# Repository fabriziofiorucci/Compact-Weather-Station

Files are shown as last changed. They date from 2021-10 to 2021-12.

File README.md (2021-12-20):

# Compact weather station

## Description

This is a MQTT-enabled, compact weather station powered by a Wemos D1 minicontroller and built with 3D-printed parts. It supports OTA updates.
The weather station is meant to be screwed on a windowsill.

Used sensors and parts are:

- Wemos D1 minicontroller
- Wind speed: Anemometer with analog voltage output (like https://www.adafruit.com/product/1733)
- Visible light: GY-30 BH1750 Ambient light sensor module
- Air quality/pollution: Digital Particle Concentration Laser Sensor PMS5003
- Rain quantity: Tipping bucket rain gauge (like https://www.bc-robotics.com/shop/tipping-rain-gauge/)
- Rain level: Capacitive soil moisture sensor
- Temperature, humidity, pressure: BME280 Humidity & Pressure Sensor
- Wind speed decoding: ADS1115 16-Bit ADC - 4 Channel with Programmable Gain Amplifier
- LM7805 linear voltage regulator
- 1x 1.8kohm resistor
- 2, 3 & 4 pins JST XH connectors
- 2 & 3 poles PCB screw terminal blocks
- 12V 2A power supply
- M3 Torx screws and bolts
- Cable glands
- 2.54mm / 1 inch PVC pipe

This project is on Thingiverse at https://www.thingiverse.com/thing:5027011

## Schematics

The circuit can be quickly built on a single layer perfboard. It can be powered by a 12V 2A power supply. The onboard LM7805 generates the 5V voltage required for most components. The BME280 sensor is powered at 3.3v directly from the Wemos D1.



## Wemos D1 sketch 

The Wemos sketch can be uploaded using Arduino IDE. The software periodically polls sensors and publishes all readings through MQTT. To reduce wear and extend service life, PMS5003 laser is switched off when not reading.
Over-The-Air updates are supported with no need to physically access the Wemos unit.

The sketch must be configured to point to your MQTT broker and to connect to your WiFi network (see "CUSTOMIZE HERE" sessions)

It relies on https://github.com/SwapBap/PMS for PMS5003 communication

## 3D components

All parts should be printed using:

- weatherproof filament (ASA or PETG)
- 3 walls
- 0.1mm layer height
- print plate adhesion raft in case it's needed

The Stevenson shield is https://www.thingiverse.com/thing:1053967 printed at 40% of the original size:

- Stevenson_screen_Side_Ring.STL (print 17 times)
- Stevenson_screen_Cover.STL (print once)
- Stevenson_screen_Base.STL (print once)
- 220mmX190mm_Internal_Bracket_for_14_Side_Rings.STL (print once)

The Anemometer 1/4-20 adapter is Anemometer_Adapter_riser_version.stl, from https://www.thingiverse.com/thing:2710360

## Complete build

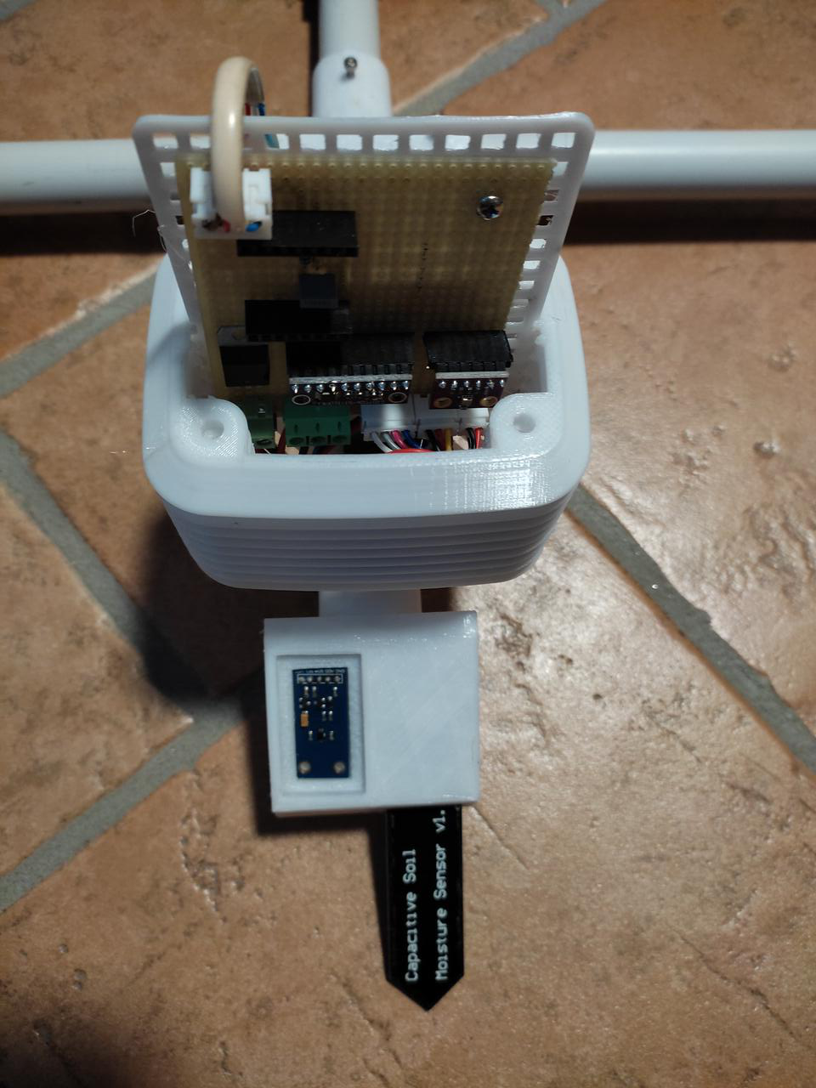
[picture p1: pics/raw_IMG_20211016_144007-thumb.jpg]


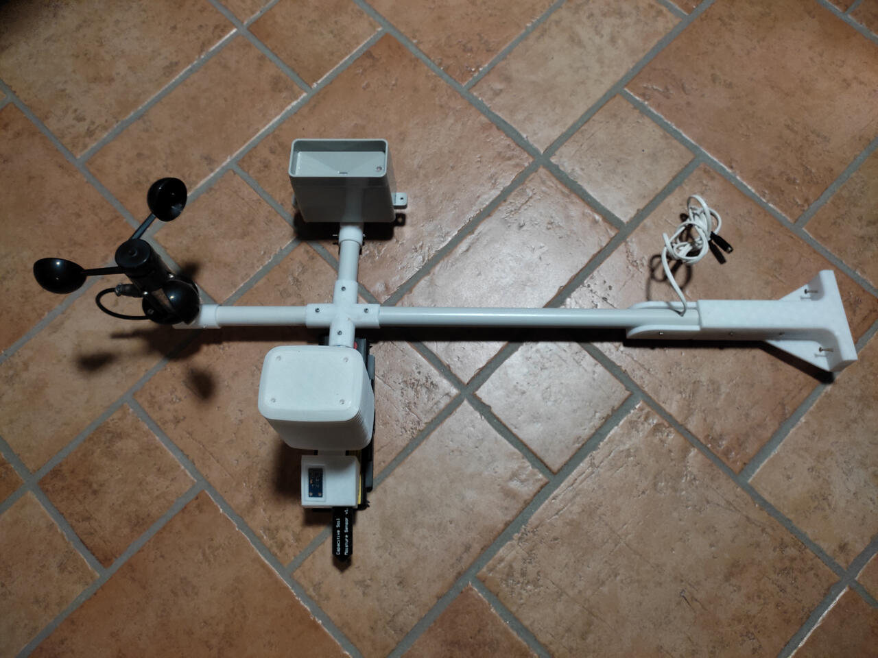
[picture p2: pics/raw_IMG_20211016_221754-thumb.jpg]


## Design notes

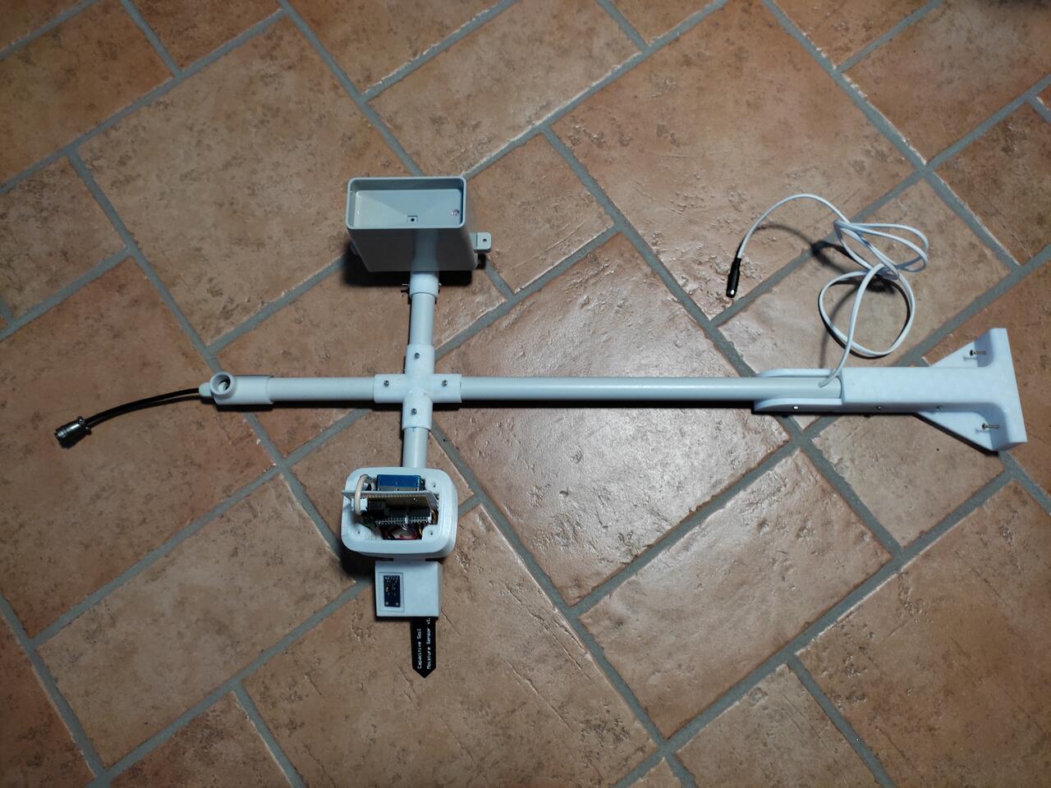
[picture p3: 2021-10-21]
pics/raw_IMG_20211016_144035-thumb.jpg

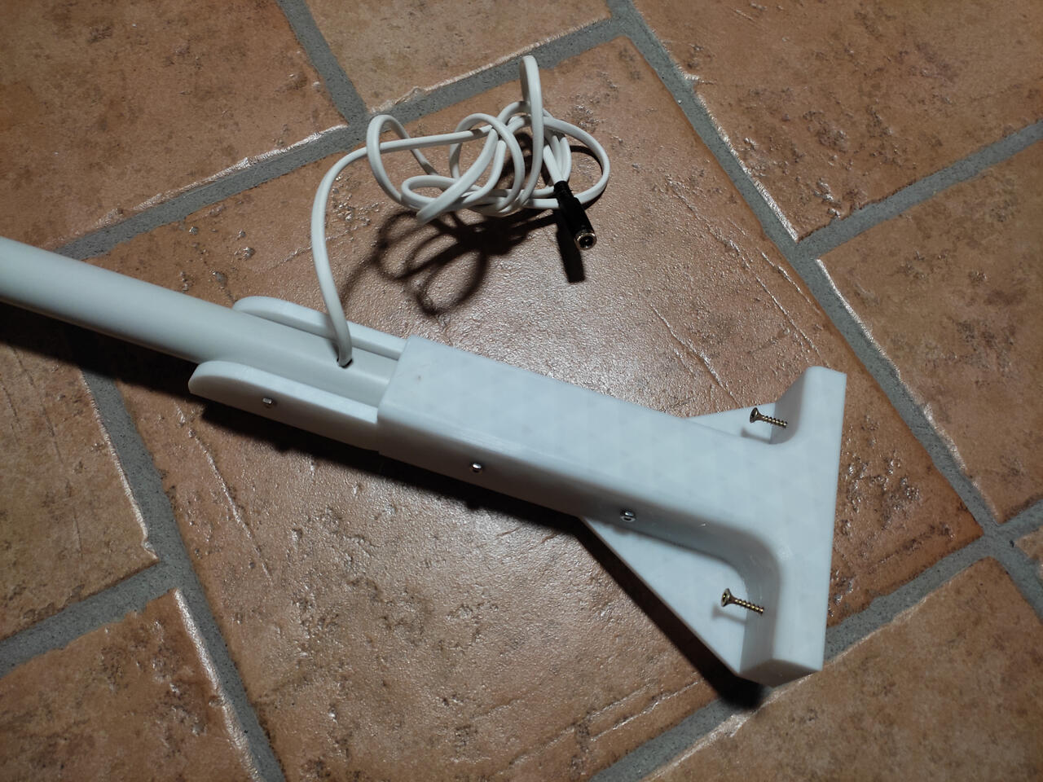
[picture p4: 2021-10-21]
pics/raw_IMG_20211016_221808-thumb.jpg

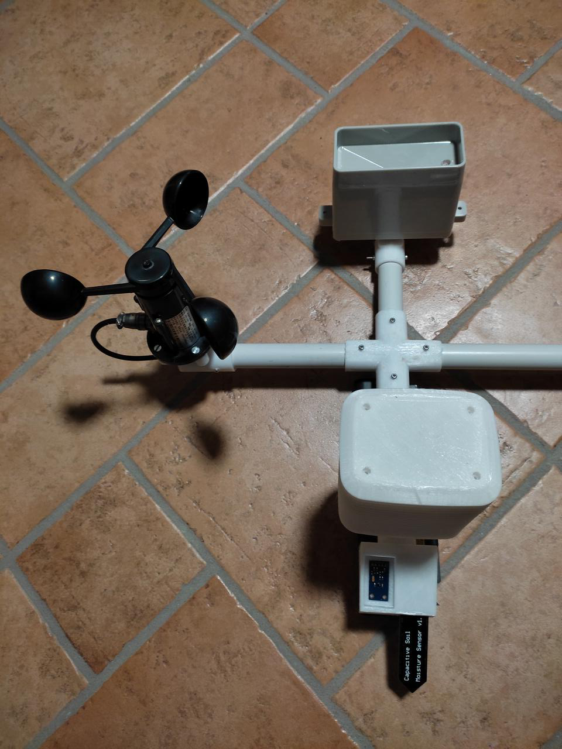
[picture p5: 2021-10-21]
pics/raw_IMG_20211016_221804-thumb.jpg

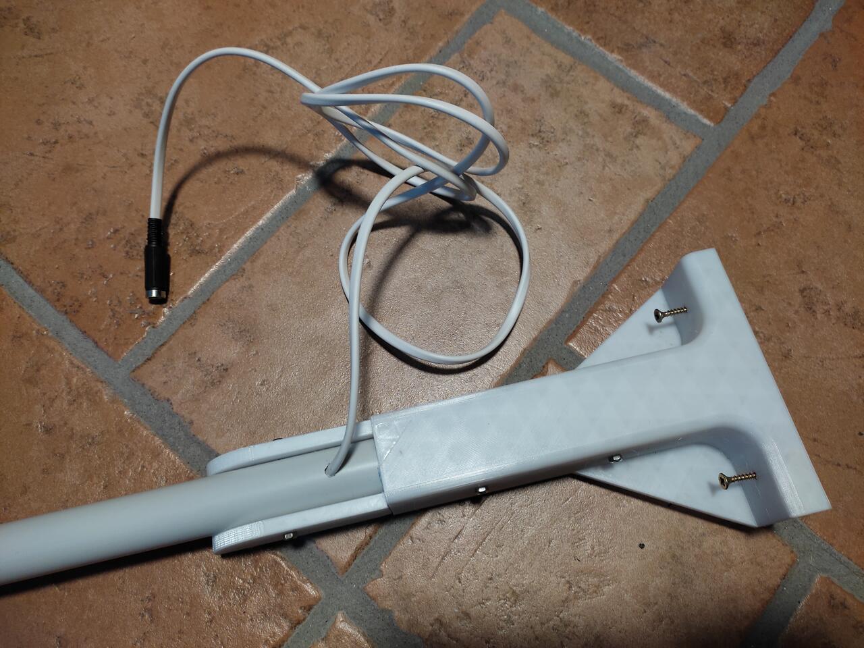
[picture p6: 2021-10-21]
pics/raw_IMG_20211016_144021-thumb.jpg

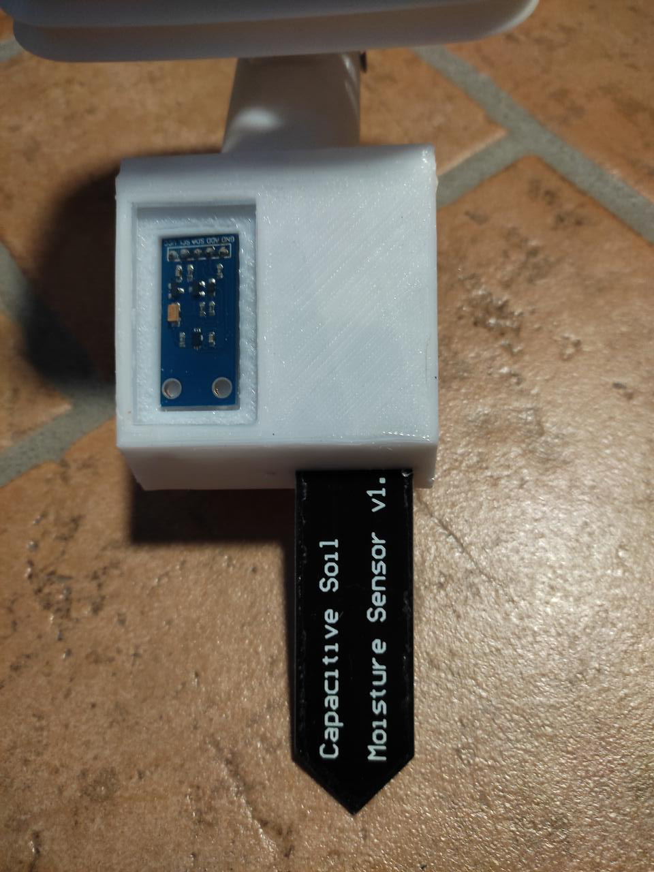
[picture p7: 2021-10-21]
pics/raw_IMG_20211016_144013-thumb.jpg

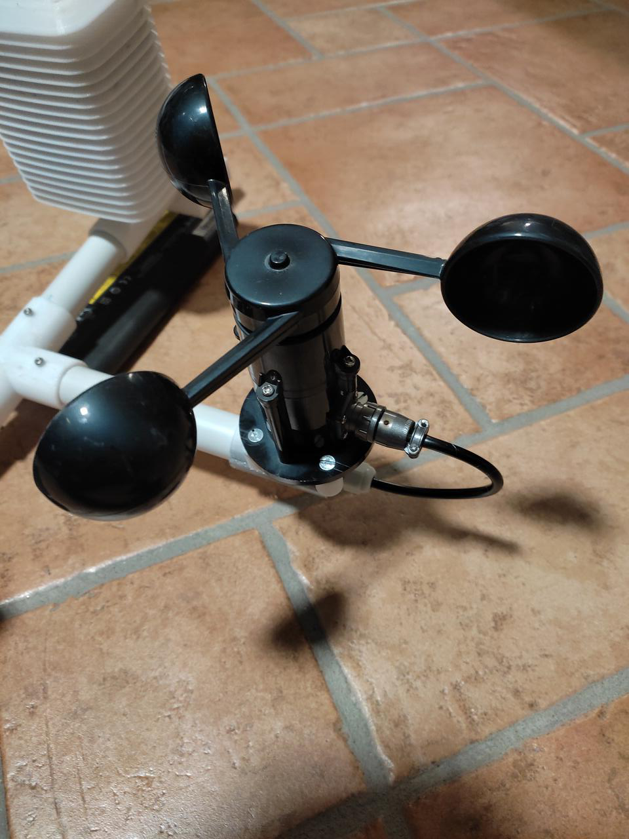
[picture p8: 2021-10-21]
pics/raw_IMG_20211016_221831-thumb.jpg

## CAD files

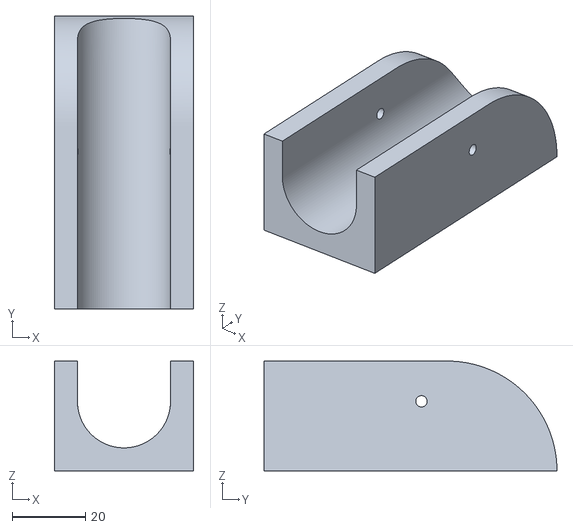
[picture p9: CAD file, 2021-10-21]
CAD/Pole support.stl
38.0 x 80.0 x 30.0

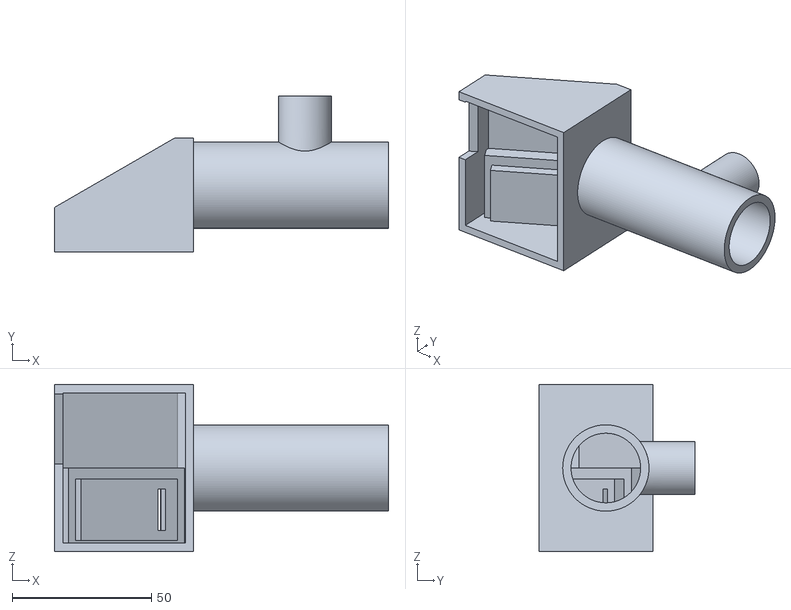
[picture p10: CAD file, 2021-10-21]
CAD/bh1750 + moisture sensor + stevenson to 1 inch pipe.stl
120.0 x 56.0 x 60.0

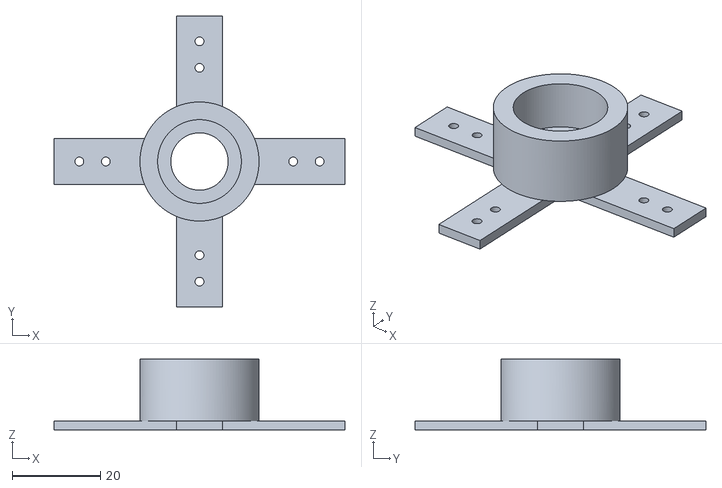
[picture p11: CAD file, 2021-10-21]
CAD/stevenson base.stl
66.0 x 66.0 x 16.0

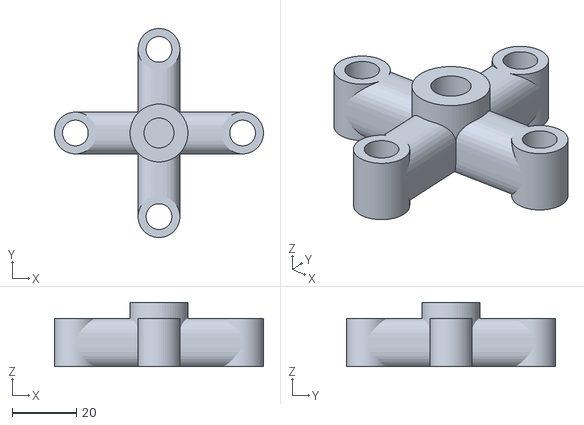
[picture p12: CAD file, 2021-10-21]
CAD/Anemometer_Adapter_riser_version.stl
65.0 x 65.0 x 20.0

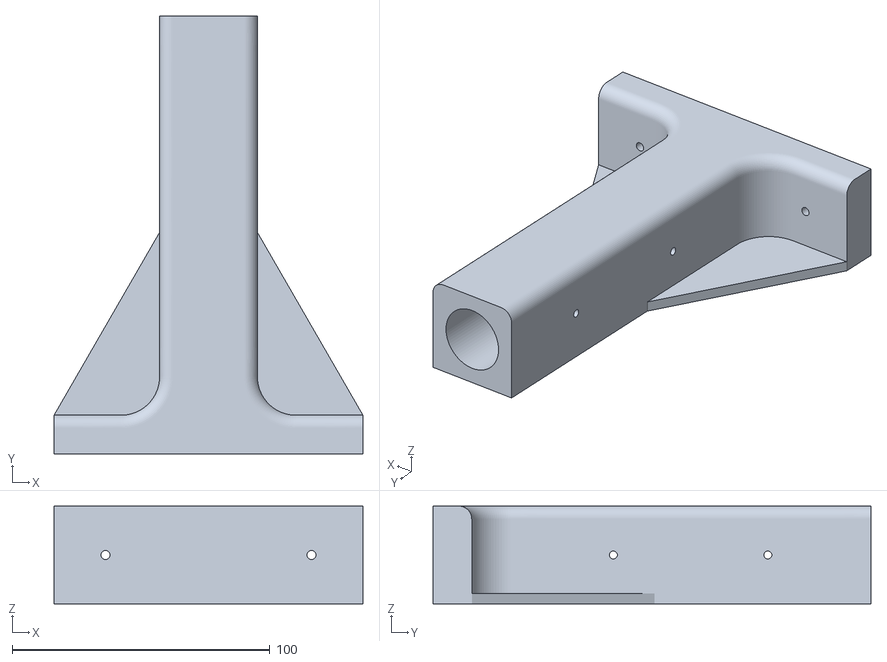
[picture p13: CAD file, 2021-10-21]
CAD/Window bracket.stl
120.0 x 170.0 x 38.0

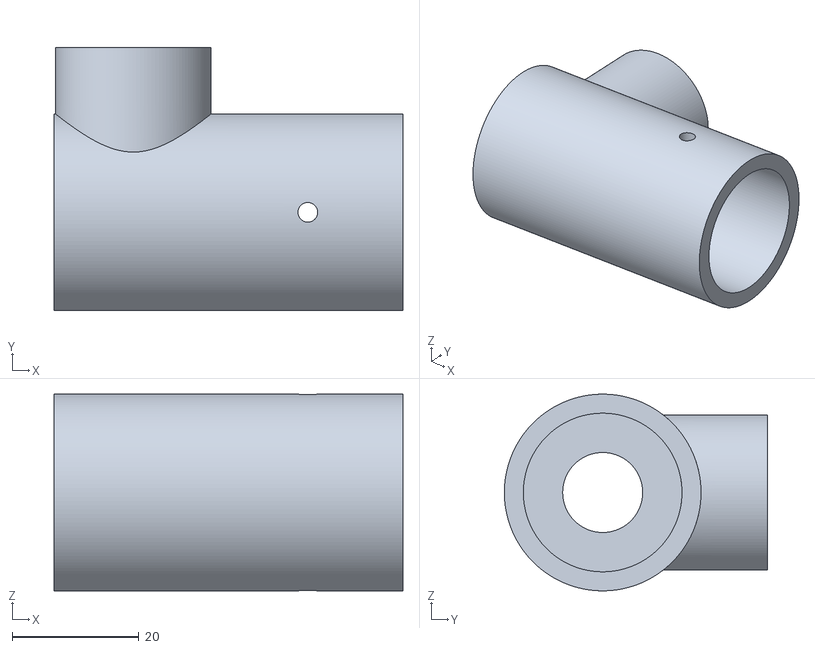
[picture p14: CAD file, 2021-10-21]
CAD/anemometer to 1 inch pipe L joint.stl
55.0 x 41.5 x 31.0

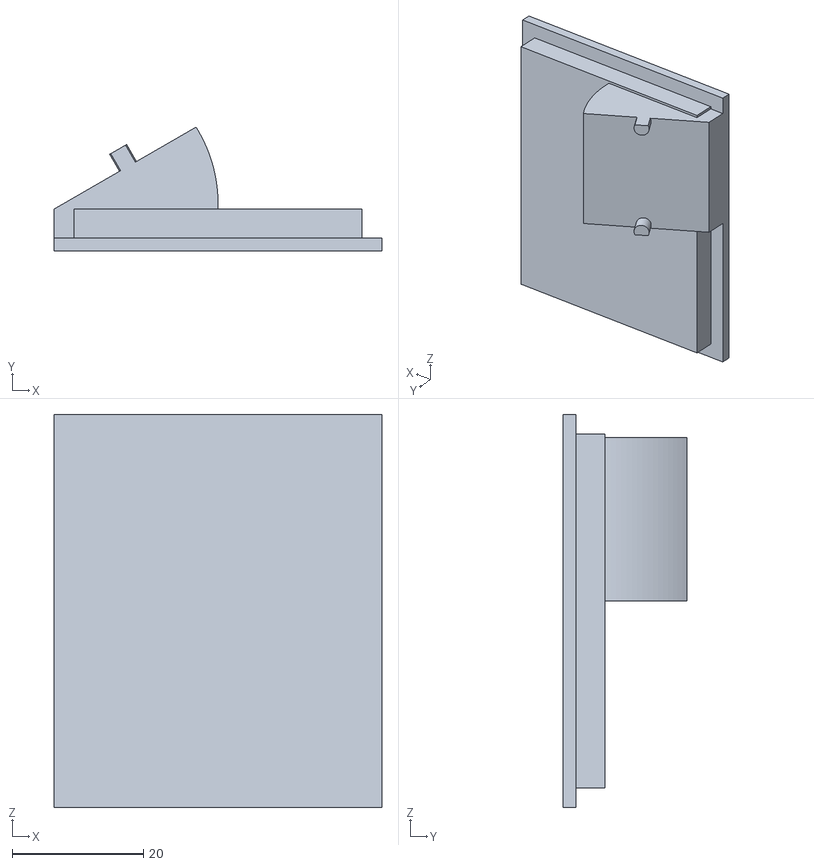
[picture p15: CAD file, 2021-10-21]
CAD/bh1750 + moisture sensor + stevenson to 1 inch pipe - lower lid.stl
50.0 x 18.9 x 60.0

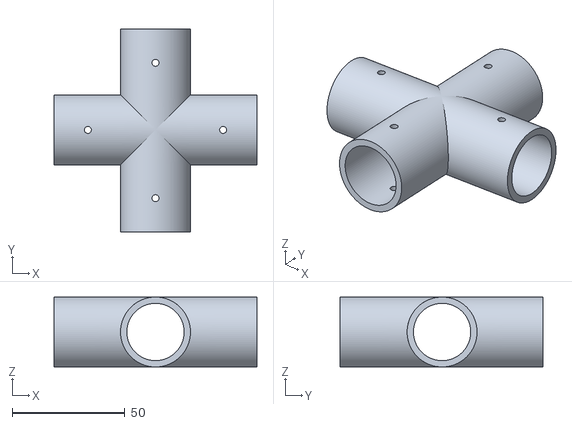
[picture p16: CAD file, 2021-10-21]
CAD/1 inch pipe X joint.stl
90.0 x 90.0 x 31.0

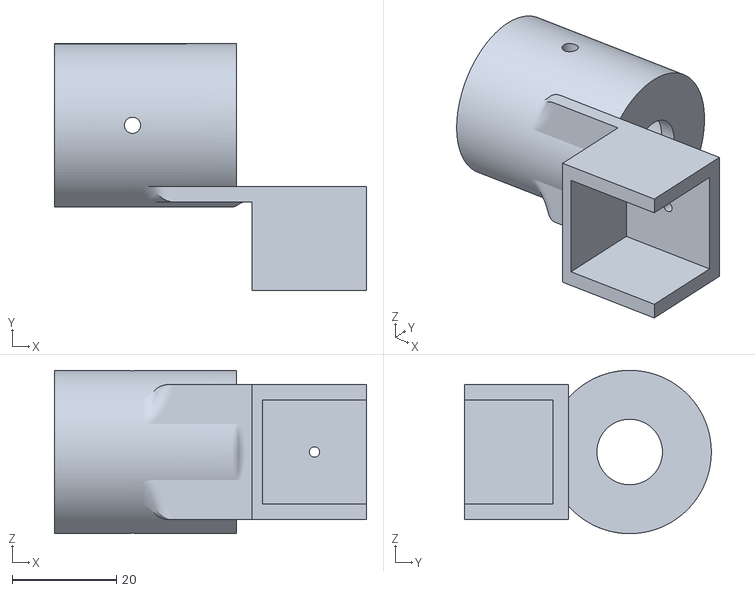
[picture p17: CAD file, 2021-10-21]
CAD/tipping bucket 1 inch pipe joint.stl
60.0 x 47.4 x 31.4

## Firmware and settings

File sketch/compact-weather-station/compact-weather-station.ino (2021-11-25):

/*
Compact Weather station

Wemos D1:
A0 = Capacitive soil moisture sensor v1.2
D1 = SCL
D2 = SDA
D3 = Rain tipping bucket (tipping bucket wires connected to D3 and GND, D3 set as INPUT_PULLUP)
D6 = to PMS5003 RX (pin 4)
D7 = to PMS5003 TX (pin 5)

I2C ids:
0x23 - GY-30 BH1750
0x48 - ADS1115
0x76 - BME280

ADS1115 gain: 2x, input range=+/-2.048v
ADS1115 addr pin = GND (0x48)
A0 - Free
A1 - Free
A2 - Free
A3 - Anemometer range 0.4-2v, vcc=9v connected to ADC through R=1.8k, max current A0=5mA - 0.4V (0 m/s wind) up to 2.0V (for 32.4m/s wind speed)

=> BME280
VCC - Brown
GND - Red
SCL - White
SDA - Blue

=> GY-30 BH1750
VCC - 3.3v
ADD->GND (I2C 0x23)

=> PMS5003
pin 4 (RX) - to Wemos D6
pin 5 (TX) - to Wemod D7 

*/

#include <Wire.h>
#include <SPI.h>
#include <Adafruit_Sensor.h>
#include <Adafruit_BME280.h>
#include <Adafruit_ADS1X15.h>
#include <ESP8266WiFi.h>
#include <PubSubClient.h>
#include <NTPClient.h>
#include <WiFiUdp.h>
#include <BH1750FVI.h>
#include <SoftwareSerial.h>
#include "PMS.h"
#include <ArduinoOTA.h>

// Particulate matter sensor
#define   PMS_STATE_ASLEEP        0   // Low power mode, laser and fan off
#define   PMS_STATE_WAKING_UP     1   // Laser and fan on, not ready yet
#define   PMS_STATE_READY         2   // Warmed up, ready to give data
uint8_t   g_pms_state           = PMS_STATE_WAKING_UP;
uint32_t  g_pms_state_start     = 0;  // Timestamp when PMS state last changed
uint8_t   g_pms_ae_readings_taken  = false;  // true/false: whether any readings have been taken
uint8_t   g_pms_ppd_readings_taken = false;  // true/false: whether PPD readings have been taken

uint16_t  g_pm1p0_sp_value      = 0;  // Standard Particle calibration pm1.0 reading
uint16_t  g_pm2p5_sp_value      = 0;  // Standard Particle calibration pm2.5 reading
uint16_t  g_pm10p0_sp_value     = 0;  // Standard Particle calibration pm10.0 reading

uint16_t  g_pm1p0_ae_value      = 0;  // Atmospheric Environment pm1.0 reading
uint16_t  g_pm2p5_ae_value      = 0;  // Atmospheric Environment pm2.5 reading
uint16_t  g_pm10p0_ae_value     = 0;  // Atmospheric Environment pm10.0 reading

uint32_t  g_pm0p3_ppd_value     = 0;  // Particles Per Deciliter pm0.3 reading
uint32_t  g_pm0p5_ppd_value     = 0;  // Particles Per Deciliter pm0.5 reading
uint32_t  g_pm1p0_ppd_value     = 0;  // Particles Per Deciliter pm1.0 reading
uint32_t  g_pm2p5_ppd_value     = 0;  // Particles Per Deciliter pm2.5 readingpm25
uint32_t  g_pm5p0_ppd_value     = 0;  // Particles Per Deciliter pm5.0 reading
uint32_t  g_pm10p0_ppd_value    = 0;  // Particles Per Deciliter pm10.0 reading

uint32_t    g_pms_warmup_period   =  30;             // Seconds to warm up PMS before reading
uint32_t    g_pms_report_period   = 120;             // Seconds between reports

const char* topicPMS5003aepm1p0="weatherstation/pms5003/ae/pm1p0";
const char* topicPMS5003aepm2p5="weatherstation/pms5003/ae/pm2p5";
const char* topicPMS5003aepm10p0="weatherstation/pms5003/ae/pm10p0";
const char* topicPMS5003ppd0p3="weatherstation/pms5003/ppd/0p3";
const char* topicPMS5003ppd0p5="weatherstation/pms5003/ppd/0p5";
const char* topicPMS5003ppd1p0="weatherstation/pms5003/ppd/1p0";
const char* topicPMS5003ppd2p5="weatherstation/pms5003/ppd/2p5";
const char* topicPMS5003ppd5p0="weatherstation/pms5003/ppd/5p0";
const char* topicPMS5003ppd10p0="weatherstation/pms5003/ppd/10p0";

char s[256];

const char* controlTopic="weatherstation/control";

// PMS5003
SoftwareSerial pmsSerial(D6, D7); // RX pin, TX pin
PMS pms(pmsSerial);                      // Use the software serial port for the PMS
PMS::DATA g_data;

#define SEALEVELPRESSURE_HPA (1013.25)

// --------------- CUSTOMIZE HERE MQTT PARAMETERS
const char* mqttServer = "mqtt-server-ip";
const char* mqttClientId="weatherstation";
const char* mqttClientPassword="mymqttpassword";

// --------------- CUSTOMIZE HERE WIFI PARAMETERS
const char* ssid = "MySSID";
const char* password = "MyWifiPassword";
IPAddress ip(192, 168, 1, 199);
IPAddress gateway(192, 168, 1, 5);
IPAddress subnet(255, 255, 255, 0);

Adafruit_BME280 bme;

// https://community.blynk.cc/t/ads1115-with-wemos-mini-d1/12215
Adafruit_ADS1115 ads;
float Voltage0 = 0.0;
float Voltage1 = 0.0;
float Voltage2 = 0.0;
float Voltage3 = 0.0;

float windSpeed = 0.0;
int capacitiveRain = 0;

// GY-30 - BH1750
BH1750FVI luxSensor(0x23);
float luxCorrectionFactor=1.2;

// NTP
WiFiUDP ntpUDP;
NTPClient timeClient(ntpUDP, "it.pool.ntp.org", 3600, 60000);

WiFiClient wifiClient;
PubSubClient mqttClient(wifiClient);

// Tipping bucket rain sensor
int TIPPING_BUCKET_PIN=D3;
long tippingBucketPulseCount=0;
unsigned long msIRQdebouncingTime = 1;
volatile unsigned long lastIRQmicros;


float readValue;
long lastMsg = 0;

long pollInterval=5000;



void setup_wifi() {
  delay(10);

  pinMode(LED_BUILTIN, OUTPUT);

  Serial.println();
  Serial.print("Connecting to ");
  Serial.println(ssid);

  WiFi.mode(WIFI_STA);
  WiFi.config(ip, gateway, subnet);
  WiFi.begin(ssid, password);

  //while (WiFi.status() != WL_CONNECTED) {
  for (int i = 0; i < 500 && WiFi.status() != WL_CONNECTED; i++) {
    digitalWrite(LED_BUILTIN, LOW);
    delay(25);
    digitalWrite(LED_BUILTIN, HIGH);
    delay(25);
    Serial.print(".");
  }

  if (WiFi.status() != WL_CONNECTED) {
    Serial.print("Restarting ESP due to loss of Wi-Fi");
    ESP.restart();
  }

  randomSeed(micros());

  Serial.println("");
  Serial.print("WiFi connected to ");
  Serial.println(ssid);
  Serial.println("IP address: ");
  Serial.println(WiFi.localIP());
}

void callback(char* topic, byte* payload, unsigned int length) {
  Serial.print("Got MQTT [");
  Serial.print(topic);
  Serial.print("] = [");
  for (int i = 0; i < length; i++) {
    Serial.print((char)payload[i]);
  }
  Serial.println("]");

  if (strcmp(topic,controlTopic)==0) {
    if ((char)payload[0]=='R') {
      Serial.println("Received MQTT reset, restarting ESP");
      ESP.restart();
    }
  }
}

void ICACHE_RAM_ATTR onTippingBucketPulse()
{
  if((long)(micros() - lastIRQmicros) >= msIRQdebouncingTime * 1000) {
    tippingBucketPulseCount++;
    lastIRQmicros = micros();
  } 
}

void setup() {
  Serial.begin(115200, SERIAL_8N1);
  Serial.println("-----------------------------------------");
  Serial.printf("Chip ID     : %08X\n", ESP.getChipId());
  Serial.printf("Core version: %s\n", ESP.getCoreVersion().c_str());
  Serial.printf("SDK version : %s\n", ESP.getSdkVersion());
  Serial.printf("CPU speed   : %dMhz\n", ESP.getCpuFreqMHz());
  Serial.printf("Free Heap   : %d\n", ESP.getFreeHeap());
  Serial.printf("Reset reason: %s\n", ESP.getResetReason().c_str());
  Serial.println("-----------------------------------------");

  setup_wifi();
  pinMode(BUILTIN_LED, OUTPUT);     // Initialize the BUILTIN_LED pin as an output

  mqttClient.setServer(mqttServer, 1883);
  mqttClient.setCallback(callback);

  bool status;
    
  status = bme.begin(0x76);  
  if (!status) {
    Serial.println("BME280 not found");
    //ESP.restart();
  }

  // The ADC input range (or gain) can be changed via the following
  // functions, but be careful never to exceed VDD +0.3V max, or to
  // exceed the upper and lower limits if you adjust the input range!
  // Setting these values incorrectly may destroy your ADC!
  //                                                                ADS1015  ADS1115
  //                                                                -------  -------
  // ads.setGain(GAIN_TWOTHIRDS);  // 2/3x gain +/- 6.144V  1 bit = 3mV      0.1875mV (default)
  // ads.setGain(GAIN_ONE);           // 1x gain   +/- 4.096V  1 bit = 2mV      0.125mV
  ads.setGain(GAIN_TWO);        // 2x gain   +/- 2.048V  1 bit = 1mV      0.0625mV
  // ads.setGain(GAIN_FOUR);       // 4x gain   +/- 1.024V  1 bit = 0.5mV    0.03125mV
  // ads.setGain(GAIN_EIGHT);      // 8x gain   +/- 0.512V  1 bit = 0.25mV   0.015625mV
  // ads.setGain(GAIN_SIXTEEN);    // 16x gain  +/- 0.256V  1 bit = 0.125mV  0.0078125mV
  
  ads.begin(0x48);

  luxSensor.powerOn();
  luxSensor.setContHighRes();
  luxSensor.setCorrectionFactor(luxCorrectionFactor);

  // PMS5003
  pmsSerial.begin(9600);   // Connection for PMS5003
  pms.passiveMode();                // Tell PMS to stop sending data automatically
  delay(100);
  Serial.println("PMS5003: wakeup");
  pms.wakeUp();                     // Tell PMS to wake up (turn on fan and laser)

  // Rain tipping bucket
  pinMode(TIPPING_BUCKET_PIN,INPUT_PULLUP);
  attachInterrupt(digitalPinToInterrupt(TIPPING_BUCKET_PIN), onTippingBucketPulse, FALLING);
  
  ArduinoOTA.setPort(8266);
  ArduinoOTA.setHostname("weatherstation");
  ArduinoOTA.setPassword((const char *)"OTApassword");

  ArduinoOTA.onStart([]() {
    Serial.println("Start");
  });
  ArduinoOTA.onEnd([]() {
    Serial.println("\nEnd");
  });
  ArduinoOTA.onProgress([](unsigned int progress, unsigned int total) {
    Serial.printf("Progress: %u%%\r", (progress / (total / 100)));
  });
  ArduinoOTA.onError([](ota_error_t error) {
    Serial.printf("Error[%u]: ", error);
    if (error == OTA_AUTH_ERROR) Serial.println("Auth Failed");
    else if (error == OTA_BEGIN_ERROR) Serial.println("Begin Failed");
    else if (error == OTA_CONNECT_ERROR) Serial.println("Connect Failed");
    else if (error == OTA_RECEIVE_ERROR) Serial.println("Receive Failed");
    else if (error == OTA_END_ERROR) Serial.println("End Failed");
  });
  ArduinoOTA.begin();
}

void reconnectMqtt() {
  while (!mqttClient.connected()) {
    String clientId = "weatherstation";

    Serial.print("Attempting MQTT connection...");
    
    if (mqttClient.connect(clientId.c_str(),mqttClientId,mqttClientPassword)) {
      Serial.println("connected to MQTT");
      mqttClient.publish("weatherstation/debug", "connected to MQTT");
    } else {
      Serial.print("failed, rc=");
      Serial.print(mqttClient.state());
      Serial.println(" try again in 5 seconds");
      delay(5000);
    }
  }
}

void pms5003Read()
{
  uint32_t time_now = millis();

  // Check if we've been in the sleep state for long enough
  if (PMS_STATE_ASLEEP == g_pms_state)
  {
    if (time_now - g_pms_state_start
        >= ((g_pms_report_period * 1000) - (g_pms_warmup_period * 1000)))
    {
      // It's time to wake up the sensor
      Serial.println("PMS5003: wakeup");
      pms.wakeUp();
      g_pms_state_start = time_now;
      g_pms_state = PMS_STATE_WAKING_UP;
    }
  }

  // Check if we've been in the waking up state for long enough
  if (PMS_STATE_WAKING_UP == g_pms_state)
  {
    //Serial.println("Checking if wakeup state is long enough");
    if (time_now - g_pms_state_start
        >= (g_pms_warmup_period * 1000))
    {
      g_pms_state_start = time_now;
      g_pms_state = PMS_STATE_READY;
    }
  }

  // Put the most recent values into globals for reference elsewhere
  if (PMS_STATE_READY == g_pms_state)
  {
    pms.requestRead();
    Serial.println("PMS5003: ready");
    if (pms.readUntil(g_data))  // Use a blocking road to make sure we get values
    {
      g_pm1p0_sp_value   = g_data.PM_SP_UG_1_0;
      g_pm2p5_sp_value   = g_data.PM_SP_UG_2_5;
      g_pm10p0_sp_value  = g_data.PM_SP_UG_10_0;

      g_pm1p0_ae_value   = g_data.PM_AE_UG_1_0;
      g_pm2p5_ae_value   = g_data.PM_AE_UG_2_5;
      g_pm10p0_ae_value  = g_data.PM_AE_UG_10_0;

      sprintf(s,"PMS5003: sp+ae [%u %u %u %u %u %u]",g_pm1p0_sp_value,g_pm2p5_sp_value,g_pm10p0_sp_value,g_pm1p0_ae_value,g_pm2p5_ae_value,g_pm10p0_ae_value);
      Serial.println(s);

      g_pms_ae_readings_taken = true;

      // This condition below should NOT be required, but currently I get all
      // 0 values for the PPD results every second time. This check only updates
      // the global values if there is a non-zero result for any of the values:
      if (g_data.PM_TOTALPARTICLES_0_3 + g_data.PM_TOTALPARTICLES_0_5
          + g_data.PM_TOTALPARTICLES_1_0 + g_data.PM_TOTALPARTICLES_2_5
          + g_data.PM_TOTALPARTICLES_5_0 + g_data.PM_TOTALPARTICLES_10_0
          != 0)
      {
        g_pm0p3_ppd_value  = g_data.PM_TOTALPARTICLES_0_3;
        g_pm0p5_ppd_value  = g_data.PM_TOTALPARTICLES_0_5;
        g_pm1p0_ppd_value  = g_data.PM_TOTALPARTICLES_1_0;
        g_pm2p5_ppd_value  = g_data.PM_TOTALPARTICLES_2_5;
        g_pm5p0_ppd_value  = g_data.PM_TOTALPARTICLES_5_0;
        g_pm10p0_ppd_value = g_data.PM_TOTALPARTICLES_10_0;
        g_pms_ppd_readings_taken = true;

        sprintf(s,"PMS5003: ppd [%u %u %u %u %u %u]",g_pm0p3_ppd_value,g_pm0p5_ppd_value,g_pm1p0_ppd_value,g_pm2p5_ppd_value,g_pm5p0_ppd_value,g_pm10p0_ppd_value);
        Serial.println(s);
      } else {
        Serial.println("PMS5003: ppd readings 0");
      }

      Serial.println("PMS5003: sleep");
      pms.sleep();

      g_pms_state_start = time_now;
      g_pms_state = PMS_STATE_ASLEEP;
    }
  }
}

void reportPMS5003ToMqtt()
{
  if (true == g_pms_ae_readings_taken)
  {
    /* Report PM1.0 AE value */
    mqttClient.publish(topicPMS5003aepm1p0, (char *) String(g_pm1p0_ae_value).c_str());

    /* Report PM2.5 AE value */
    mqttClient.publish(topicPMS5003aepm2p5, (char *) String(g_pm2p5_ae_value).c_str());

    /* Report PM10.0 AE value */
    mqttClient.publish(topicPMS5003aepm10p0, (char *) String(g_pm10p0_ae_value).c_str());

    g_pms_ae_readings_taken=false;
  }

  if (true == g_pms_ppd_readings_taken)
  {
    /* Report PM0.3 PPD value */
    mqttClient.publish(topicPMS5003ppd0p3,(char *) String(g_pm0p3_ppd_value).c_str());

    /* Report PM0.5 PPD value */
    mqttClient.publish(topicPMS5003ppd0p5,(char *) String(g_pm0p5_ppd_value).c_str());

    /* Report PM1.0 PPD value */
    mqttClient.publish(topicPMS5003ppd1p0,(char *) String(g_pm1p0_ppd_value).c_str());

    /* Report PM2.5 PPD value */
    mqttClient.publish(topicPMS5003ppd2p5,(char *) String(g_pm2p5_ppd_value).c_str());

    /* Report PM5.0 PPD value */
    mqttClient.publish(topicPMS5003ppd5p0,(char *) String(g_pm5p0_ppd_value).c_str());

    /* Report PM10.0 PPD value */
    mqttClient.publish(topicPMS5003ppd10p0,(char *) String(g_pm10p0_ppd_value).c_str());
    
    g_pms_ppd_readings_taken=false;
  }
}

void readADS1115()
{
  int16_t adc0, adc1, adc2, adc3;

  adc0 = ads.readADC_SingleEnded(0);
  adc1 = ads.readADC_SingleEnded(1);
  adc2 = ads.readADC_SingleEnded(2);
  adc3 = ads.readADC_SingleEnded(3);

  Serial.print("ADS1115 A0 : ");
  Serial.println(adc0);
  Serial.print("ADS1115 A1 : ");
  Serial.println(adc1);
  Serial.print("ADS1115 A2 : ");
  Serial.println(adc2);
  Serial.print("ADS1115 A3 : ");
  Serial.println(adc3);
  
  Voltage0 = (adc0 * 0.0625)/1000.0;
  Voltage1 = (adc1 * 0.0625)/1000.0; 
  Voltage2 = (adc2 * 0.0625)/1000.0;
  Voltage3 = (adc3 * 0.0625)/1000.0;
}

void loop() { 
  ArduinoOTA.handle();

  long now = millis();
  if (now - lastMsg > pollInterval) {
    lastMsg = now;
  
  if (!mqttClient.connected()) {
    reconnectMqtt();
  }

  mqttClient.loop();
  pms5003Read();

  Serial.println("-----------");

  digitalWrite(LED_BUILTIN, LOW);

  readValue=bme.readTemperature();
  mqttClient.publish("weatherstation/temperature", (char *) String(readValue).c_str());
  Serial.print("Temperature:   ");
  Serial.print(readValue, 2);
  Serial.println(" °C");

  readValue=bme.readPressure() / 100.0F;
  mqttClient.publish("weatherstation/pressure", (char *) String(readValue).c_str());
  Serial.print("Pressure   :   ");
  Serial.print(readValue, 2);
  Serial.println(" hPa");

  readValue=bme.readAltitude(SEALEVELPRESSURE_HPA);
  mqttClient.publish("weatherstation/altitude", (char *) String(readValue).c_str());
  Serial.print("Altitude   :   ");
  Serial.print(readValue, 2);
  Serial.println(" m");

  readValue=bme.readHumidity();
  mqttClient.publish("weatherstation/humidity", (char *) String(readValue).c_str());
  Serial.print("Humidity   :   ");
  Serial.print(readValue, 2);
  Serial.println(" %");

  readADS1115();

  Serial.print("A0 (free)  : ");
  Serial.println((float)(Voltage0),2);
  
  Serial.print("A1  (free)  : ");
  Serial.println((float)(Voltage1),2);

  Serial.print("A2 (free)  : ");
  Serial.println((float)(Voltage2),2);
  
  Serial.print("A3 (wind)  : ");
  Serial.print((float)(Voltage3),2);
  Serial.print("  Speed: ");
  windSpeed=(Voltage3-0.39)*32.4/1.6;
  Serial.println((float)(windSpeed),2);
  mqttClient.publish("weatherstation/wind/speed", (char *) String(windSpeed).c_str());

  if(luxSensor.isReady()) {
    float luxLight=luxSensor.getLux();

    Serial.print("Light      : ");
    Serial.print(luxLight,2);
    Serial.println(" Lx");
    mqttClient.publish("weatherstation/light", (char *)String(luxLight).c_str());
  }

  capacitiveRain=(814-(float)analogRead(A0))/814*100;
  Serial.print("Capacitive rain: ");
  Serial.println(capacitiveRain);
  mqttClient.publish("weatherstation/rain/capacitive", (char *)String(capacitiveRain).c_str());

  // Rain tipping bucket
  long tippingBucketReading=tippingBucketPulseCount;
  tippingBucketPulseCount=0;
  Serial.print("Rain tipping   :");
  Serial.println(tippingBucketReading);
  mqttClient.publish("weatherstation/rain/tipping", (char *)String(tippingBucketReading).c_str());

  // PMS5003
  reportPMS5003ToMqtt();
  
  digitalWrite(LED_BUILTIN, HIGH);
  }
}

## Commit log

2021-12-20 Schematics updated
2022-01-30 Fixed bug in schematics
